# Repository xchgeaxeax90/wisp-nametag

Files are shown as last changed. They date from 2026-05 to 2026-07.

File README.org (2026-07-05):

#+title: Wisp Light-up Nametag

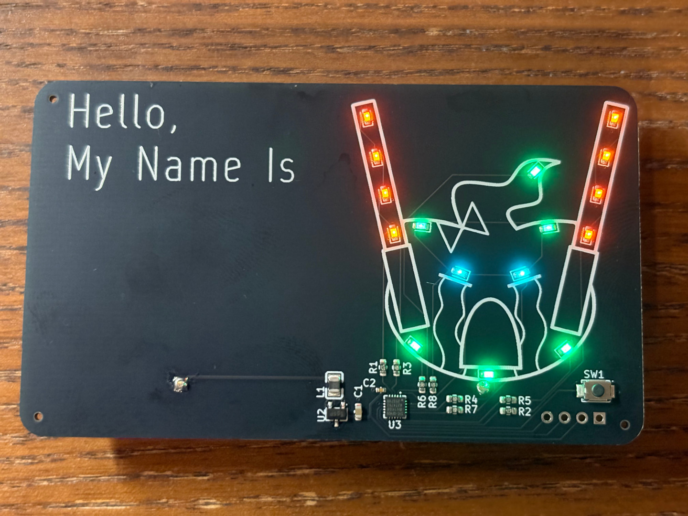
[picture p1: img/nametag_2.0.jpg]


This repository contains the PCB design and software for the light up
nametag I will be giving out at Offkai Expo 2026. 

* Usage
** Battery

*NOTE: Please be very careful to insert the battery with the correct polarity in the battery holder. Failure to do so may result in destruction of the device*

The Badge is powered by a 1.5V AAA battery. While I have not tested it, it should be compatible with rechargable AAA cells or lithium rechargable cells, provided the battery voltage is below 3 volts.

While powered down, the badge draws a small amount of current from the battery at all times. When storing the badge for long periods of time (weeks-months), please remove the battery so as to avoid draining the battery or causing it to leak.

*** User Interface

- Tap the button on the bottom right to change the blink pattern
- Press and hold the button on the bottom right for about 2 seconds, then release to enter brightness mode. The LEDs will stop blinking and remain on continuously
- When in brightness mode, tap the button to change the brightness
- To exit brightness mode, press and hold the button for about 2 seconds, then release. The LEDs should begin blinking again
- To power off the device, press and hold the button until the LEDs turn off
- To power the device back on, tap the button again

* Manufacture

** Hardware
The PCBs I made were ordered from [[https://jlcpcb.com][JLCPCB]], through their PCB Assembly
service. The design files under the [[https://github.com/xchgeaxeax90/wisp-nametag/releases/tag/v2.0][v2.0 Manufacturing Files]] release
can be uploaded to JLCPCB's automatic quote system to order either
bare PCBs or assembled boards.

*** Parts

The Bill of Materials is below. When viewing the BOM from Kicad, the JLCPCB/LCSC part ids should be taken as the reference, some of the part numbers in the schematic are incorrect

| Part Name            | Designator              | Comment                                                                |
|----------------------+-------------------------+------------------------------------------------------------------------|
| TZ-P2-0603GTCS1-0.6T | D9,D10,D11,D12,D13,D14  | 0603 SMD LED – Emerald Green 520nm                                     |
| TS-1088-AR02016      | SW1                     | 3.9x3.0mm SPST Momentary Button                                        |
| CL10A226MQ8NRNC      | C1                      | 0603 22uf ceramic capacitor                                            |
| MPL2016S2R2MHT       | L1                      | 0806 2.2 uH inductor                                                   |
| BL8536CB3TR36        | U2                      | 0.9V-3.3V Ultra Low Voltage Boost Converter                            |
| 0603WAF470JT5E       | R1,R2                   | 0603 47 Ohm Resistor                                                   |
| STC8H1K08-36I-QFN20  | U3                      | STC8H1K08 24MHz microcontroller                                        |
| CL05B104KO5NNNC      | C2                      | 0402 100nF Capacitor                                                   |
| LTST-C190KFKT        | D1,D2,D3,D4,D5,D6,D7,D8 | 0603 SMD LED – Orange 605nm                                            |
| SMLD12E3N1WT86       | D15,D16                 | 0603 SMD LED – Cyan 496nm                                              |
| 0603WAF3000T5E       | R3,R4,R5,R6,R7,R8       | 0603 300 Ohm Resistor                                                  |
| 2466                 | BT1                     | AAA Battery Holder (not included in JLCPCB quote, hand solder on back) |

Note: If manufacturing this yourself, consider using the
SMLD12E2N1WT86 505nm Blue-Green LED in place of the 520 Emerald Green
LED. It looks much closer to mint green, but is much more difficult
and expensive to source

** Software

The software loaded on the badges I gave (or will give) out can be
found at the [[https://github.com/xchgeaxeax90/wisp-nametag/releases/tag/v2.0-software][v2.0 Software]] release. This contains the entire source
code as well as prebuilt binaries that can be loaded directly onto the
boards.

*** Programming

The microcontroller can be programmed using a 3.3V USB to UART cable and the [[https://github.com/grigorig/stcgal][STCGal programmer software]].

1. Completely remove power from the board. The board cannot just be put to sleep using the button, it must be entirely powered off, with the battery removed
2. Connect the microcontroller's TX and RX pins to the UART. These pins can be found on the programming header on the bottom left of the PCB when viewed from the back. If you're good, you can likely do this by just shoving pins in the holes instead of soldering them in place.
3. Start =stcgal=, replacing =/dev/ttyUSB0= with your USB to UART's serial port device 
   
#+BEGIN_SRC bash
  stcgal -p /dev/ttyUSB0 -P stc8g --trim 24000 path/to/app.hex
#+END_SRC

4. Power on the board - I like to use alligator clips to clip directly on to the battery terminals, but you can also just insert the battery

5. The programmer should automatically begin downloading the code to the microcontroller

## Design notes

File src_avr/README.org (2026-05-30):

* Datasheets and application notes:
  - AVR16DD20 Datasheet: https://ww1.microchip.com/downloads/aemDocuments/documents/MCU08/ProductDocuments/DataSheets/AVR32-16DD20-14-Complete-DataSheet-DS40002413.pdf
  - Getting started with TCA Technical Brief: https://ww1.microchip.com/downloads/aemDocuments/documents/MCU08/ApplicationNotes/ApplicationNotes/TB3217-Getting-Started-with-TCA-DS90003217.pdf
    - This will be used to drive the 6 PWM channels controlling the
      lights on the face. Two sets of lights (the eyes and top l/r)
      are shared and will be multiplexed
  - Getting started with TCB Technical Brief: https://ww1.microchip.com/downloads/en/DeviceDoc/TB3214-Getting-Started-with-TCB-90003214A.pdf
    - This timer (of which there are two) will be used to generate a
      periodic interrupt to switch between the eye and top l/r multiplexing
  - Getting started with TCD Technical Brief: https://ww1.microchip.com/downloads/aemDocuments/documents/MCU08/ApplicationNotes/ApplicationNotes/TB3212-Getting-Started-with-TCD-DS90003212.pdf
    - This timer will be used to generate the PWM signals for the penlights
  - Getting started with RTC Technical Brief: https://ww1.microchip.com/downloads/en/Appnotes/TB3213-Getting-Started-with-RTC-DS90003213B.pdf
    - This may or may not be used to trigger a PWM setting update -
      Either this, the second timer B, or an extra counter and hook
      into the multiplex interrupt will do it
  - Getting started with CCL Technical Brief: https://ww1.microchip.com/downloads/en/AppNotes/TB3218-Getting-Started-with-CCL-90003218A.pdf
    - This might be needed to debounce/filter the signal from the
      button (which conveniently is on a CCL input, totally by accident)
  
  - Hacking an Attiny817XPlained to be a UPDI programmer: https://www.jsykora.info/2019/04/avr-updi-programmer-from-attiny817-xplained-mini/
  - Generating PWM signals with TCD Appnote: https://ww1.microchip.com/downloads/aemDocuments/documents/MCU08/ApplicationNotes/ApplicationNotes/Generating-PWMSignals-Using-TCD-with-HF-Input-DS90003236C.pdf

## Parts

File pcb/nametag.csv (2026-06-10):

Comment | Designator | Footprint | LCSC
Battery_Cell | BT1 | Battery:BatteryHolder_Keystone_2466_1xAAA
GMC10X5R226M10NT | C1 | Capacitor_SMD:C_0603_1608Metric | C59461
100n | C2 | Capacitor_SMD:C_0402_1005Metric | C1525
LTST-C190KFKT | D1,D2,D3,D4,D5,D6,D7,D8 | LED_SMD:LED_0603_1608Metric | C157740
SMLD12E2N1WT86 | D15,D16 | LED_SMD:LED_0603_1608Metric | C2846641
SMLD12E3N1WT86 | D9,D10,D11,D12,D13,D14 | LED_SMD:LED_0603_1608Metric | C779453
WIP201612S-2R2MLDG | L1 | EasyEDA:L0806 | C42215
47 | R1,R2 | Resistor_SMD:R_0603_1608Metric | C23182
300 | R3,R4,R5,R6,R7,R8 | Resistor_SMD:R_0603_1608Metric | C23025
TS-1088-AR02016 | SW1 | EasyEDA:SW-SMD_L3.9-W3.0-P4.45
TestPoint | TP1,TP2,TP3,TP4 | TestPoint:TestPoint_Pad_D1.0mm
BL8536CB3TR36 | U2 | EasyEDA:SOT-23-3_L2.9-W1.6-P1.90-LS2.8-BR
STC8H1K08-QFN20 | U3 | EasyEDA:QFN-20_L3.0-W3.0-P0.40-BL-EP1.7 | C915674

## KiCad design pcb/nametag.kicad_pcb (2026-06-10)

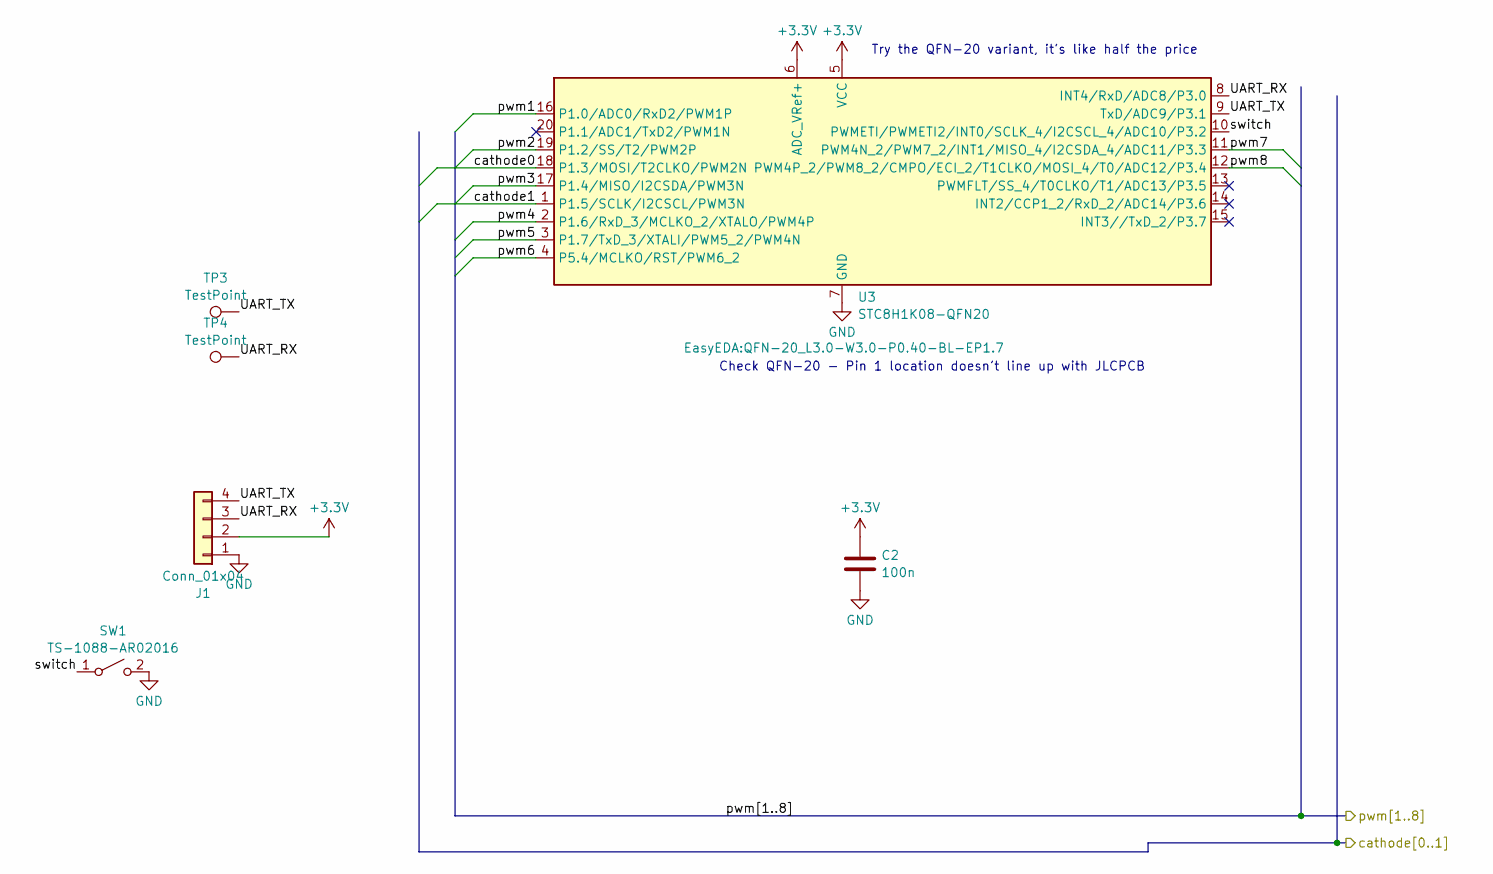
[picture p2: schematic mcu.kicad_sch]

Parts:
C2: 100n; C_0402_1005Metric; LCSC C1525
J1: Conn_01x04; PinSocket_1x04_P2.54mm_Vertical
SW1: TS-1088-AR02016; SW-SMD_L3.9-W3.0-P4.45
TP3, TP4: TestPoint; TestPoint_Pad_D1.0mm
U3: STC8H1K08-QFN20; QFN-20_L3.0-W3.0-P0.40-BL-EP1.7; LCSC C915674

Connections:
+3.3V: C2.1, J1.2, U3.5 (VCC), U3.6 (ADC_VRef+); also elsewhere on the board
/Mcu/UART_RX: J1.3, TP4.1 (1_1), U3.8 (INT4/RxD/ADC8/P3.0)
/Mcu/UART_TX: J1.4, TP3.1 (1_1), U3.9 (TxD/ADC9/P3.1)
/Mcu/cathode0: U3.18 (P1.3/MOSI/T2CLKO/PWM2N); also elsewhere on the board
/Mcu/cathode1: U3.1 (P1.5/SCLK/I2CSCL/PWM3N); also elsewhere on the board
/Mcu/pwm1: U3.16 (P1.0/ADC0/RxD2/PWM1P); also elsewhere on the board
/Mcu/pwm2: U3.19 (P1.2/SS/T2/PWM2P); also elsewhere on the board
/Mcu/pwm3: U3.17 (P1.4/MISO/I2CSDA/PWM3N); also elsewhere on the board
/Mcu/pwm4: U3.2 (P1.6/RxD_3/MCLKO_2/XTALO/PWM4P); also elsewhere on the board
/Mcu/pwm5: U3.3 (P1.7/TxD_3/XTALI/PWM5_2/PWM4N); also elsewhere on the board
/Mcu/pwm6: U3.4 (P5.4/MCLKO/RST/PWM6_2); also elsewhere on the board
/Mcu/pwm7: U3.11 (PWM4N_2/PWM7_2/INT1/MISO_4/I2CSDA_4/ADC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); also elsewhere on the board
/Mcu/pwm8: U3.12 (PWM4P_2/PWM8_2/CMPO/ECI_2/T1CLKO/MOSI_4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); also elsewhere on the board
/Mcu/switch: SW1.1 (A), U3.10 (PWMETI/PWMETI2/INT0/SCLK_4/I2CSCL_4/ADC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)
GND: C2.2, J1.1, SW1.2 (B), U3.7 (GND), U3.21 (EP); also elsewhere on the board

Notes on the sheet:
Check QFN-20 - Pin 1 location doesn't line up with JLCPCB
Try the QFN-20 variant, it's like half the price

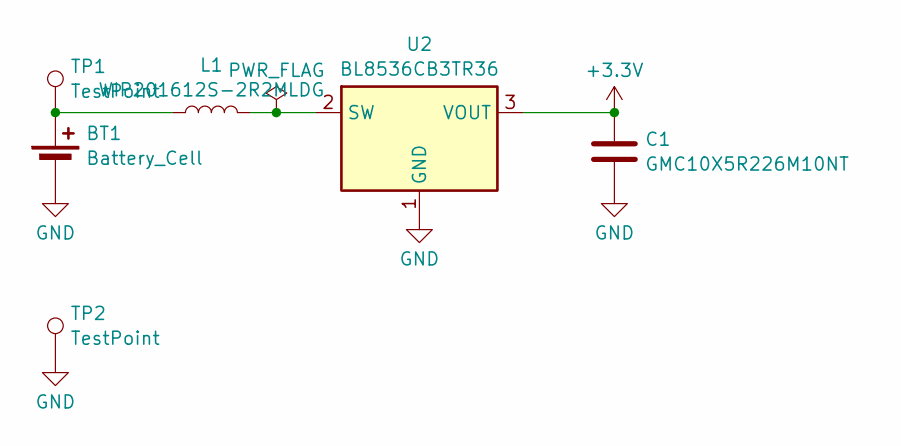
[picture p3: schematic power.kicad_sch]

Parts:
BT1: Battery_Cell; BatteryHolder_Keystone_2466_1xAAA
C1: GMC10X5R226M10NT; C_0603_1608Metric; LCSC C59461
L1: WIP201612S-2R2MLDG; L0806; LCSC C42215
TP1, TP2: TestPoint; TestPoint_Pad_D1.0mm
U2: BL8536CB3TR36; SOT-23-3_L2.9-W1.6-P1.90-LS2.8-BR

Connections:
+3.3V: C1.1, U2.3 (VOUT); also elsewhere on the board
GND: BT1.2 (-), C1.2, TP2.1 (1_1), U2.1 (GND); also elsewhere on the board
unnamed: BT1.1 (+), L1.1, TP1.1 (1_1)
unnamed: L1.2, U2.2 (SW)

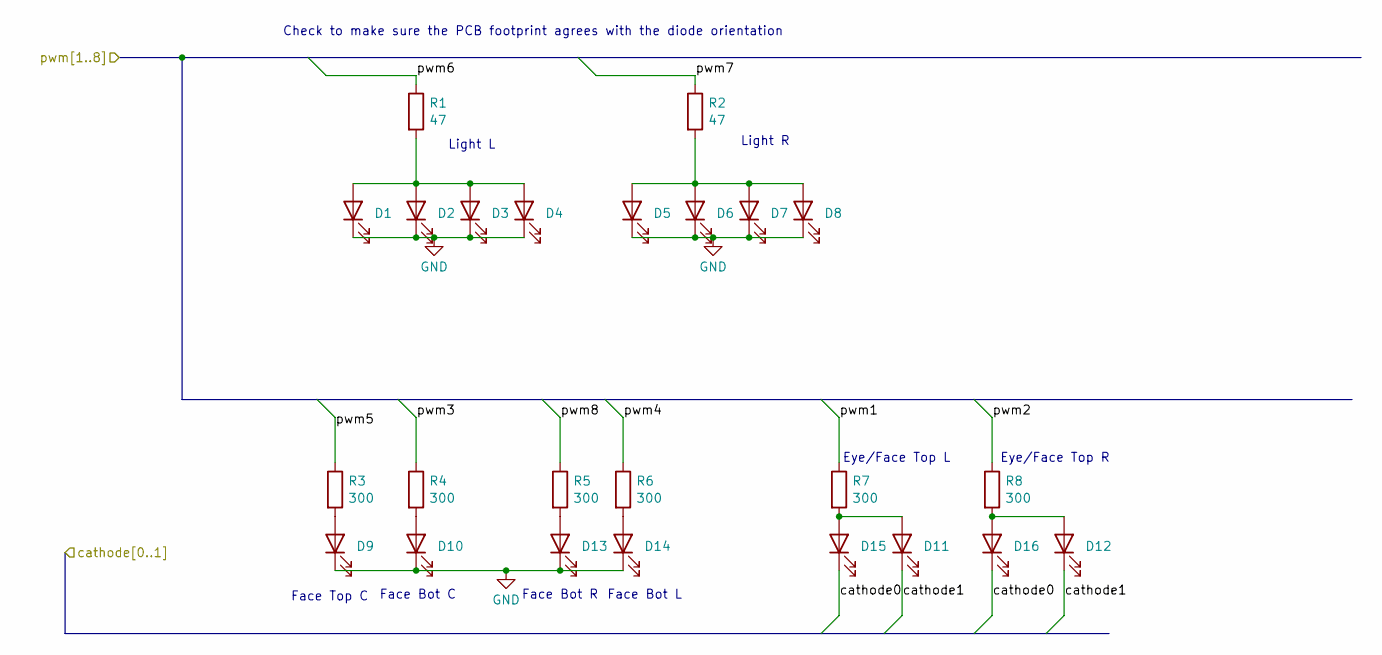
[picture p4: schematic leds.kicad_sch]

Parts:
D1, D2, D3, D4, D5, D6, D7, D8: LTST-C190KFKT; LED_0603_1608Metric; LCSC C157740
D9, D10, D11, D12, D13, D14: SMLD12E3N1WT86; LED_0603_1608Metric; LCSC C779453
D15, D16: SMLD12E2N1WT86; LED_0603_1608Metric; LCSC C2846641
R1, R2: 47; R_0603_1608Metric; LCSC C23182
R3, R4, R5, R6, R7, R8: 300; R_0603_1608Metric; LCSC C23025

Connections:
/Mcu/cathode0: D15.1 (K), D16.1 (K); also elsewhere on the board
/Mcu/cathode1: D11.1 (K), D12.1 (K); also elsewhere on the board
/Mcu/pwm1: R7.1; also elsewhere on the board
/Mcu/pwm2: R8.1; also elsewhere on the board
/Mcu/pwm3: R4.1; also elsewhere on the board
/Mcu/pwm4: R6.1; also elsewhere on the board
/Mcu/pwm5: R3.1; also elsewhere on the board
/Mcu/pwm6: R1.1; also elsewhere on the board
/Mcu/pwm7: R2.1; also elsewhere on the board
/Mcu/pwm8: R5.1; also elsewhere on the board
GND: D1.1 (K), D2.1 (K), D3.1 (K), D4.1 (K), D5.1 (K), D6.1 (K), D7.1 (K), D8.1 (K), D9.1 (K), D10.1 (K), D13.1 (K), D14.1 (K); also elsewhere on the board
unnamed: D1.2 (A), D2.2 (A), D3.2 (A), D4.2 (A), R1.2
unnamed: D5.2 (A), D6.2 (A), D7.2 (A), D8.2 (A), R2.2
unnamed: D9.2 (A), R3.2
unnamed: D10.2 (A), R4.2
unnamed: D11.2 (A), D15.2 (A), R7.2
unnamed: D12.2 (A), D16.2 (A), R8.2
unnamed: D13.2 (A), R5.2
unnamed: D14.2 (A), R6.2

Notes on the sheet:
Face Bot L
Eye/Face Top R
Light L
Light R
Face Bot C
Check to make sure the PCB footprint agrees with the diode orientation
Eye/Face Top L
Face Bot R
Face Top C

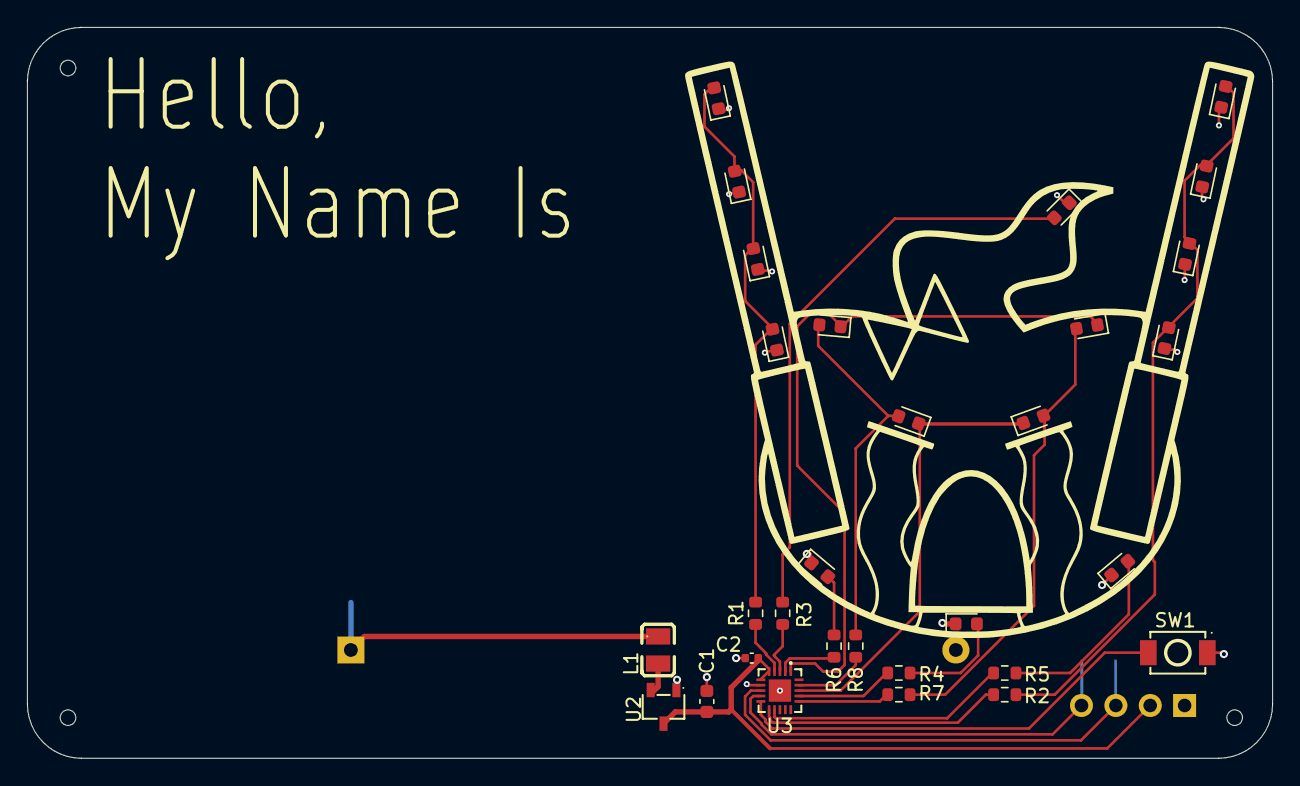
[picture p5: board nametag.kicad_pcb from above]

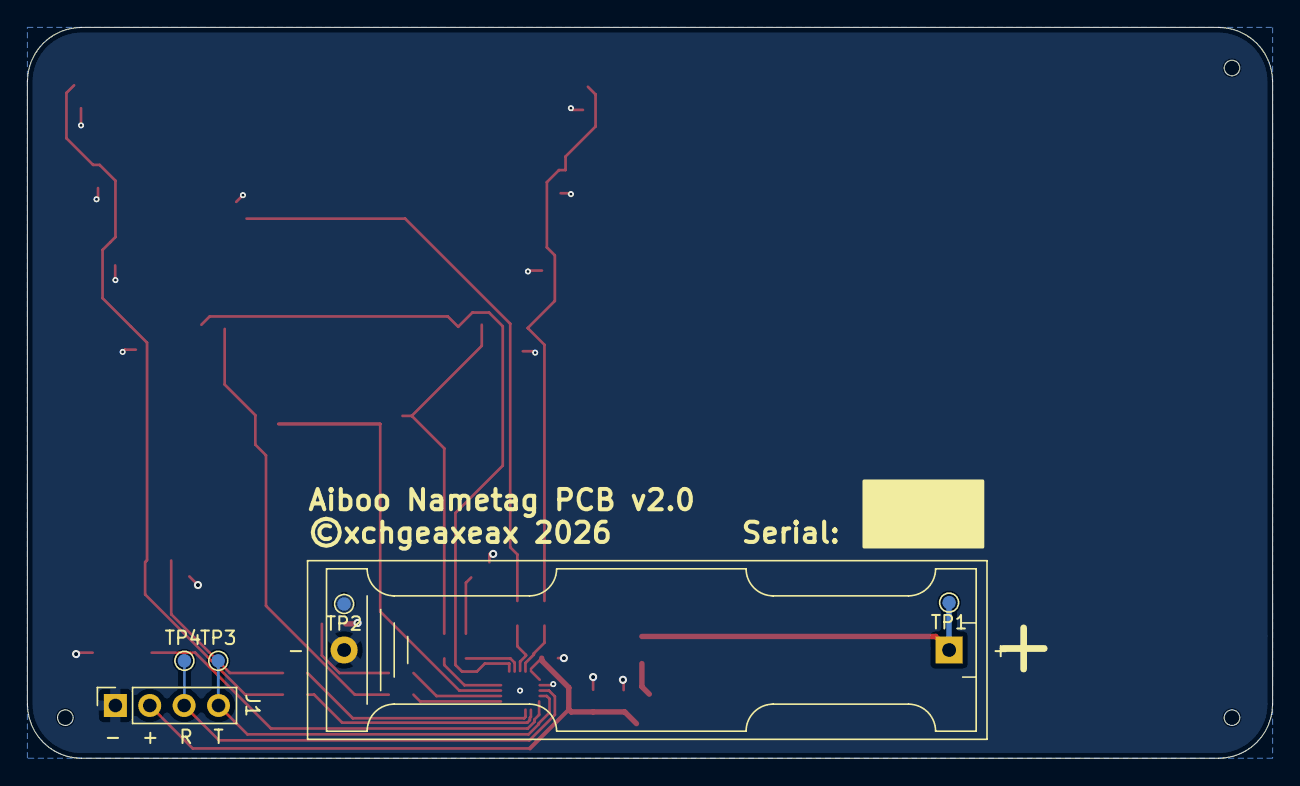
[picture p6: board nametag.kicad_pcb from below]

Board: 2 copper layers, 92.0 x 54.0 mm, 39 parts (6 on the bottom side), 25 nets.

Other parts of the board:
HO1, HO2, HO3: JLC PCBA Mounting Hole

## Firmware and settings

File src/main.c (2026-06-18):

#include "fw_hal.h"
#include "pins.h"
#include "pwm.h"
#include "timer.h"
#include "animation.h"
#include "state_machine.h"
#include "debug.h"

/* TODO determine if we actually need the button state bit */
volatile __idata uint16_t button_timeout = 0;
volatile __BIT button_state = 0;
void poll_button(void){
    /* Button is active low */
    if(!BUTTON_PIN_BIT){
        if(!button_state){
            button_timeout = 0;
        } else {
            button_timeout += 1;
        }
        button_state = 1;
    } else {
        button_state = 0;
    }
}

/* Selects which cathode to enable */

// Called periodically by TCB0 to update the multiplexing for the eyes and top LEDs

static volatile __BIT eye_en = 0;
INTERRUPT_USING(Timer2_Routine, EXTI_VectTimer2, 1) {
    uint8_t p_sw2_save = P_SW2;
    poll_button();
    /* Disable cathodes */
    if(update_animation()){

        write_pwm();
    }
    /* Disable both cathodes between PWM setting update and when the
    setting is loaded to the capture compare unit */
    CATHODE0_PIN_BIT = SET;
    CATHODE1_PIN_BIT = SET;
    write_pwm_multiplexed(eye_en);
    /* Enable the interrupt for PWM overflow to synchronize cathode updates to PWM period */

    /* Enable the PWM update interrupt so the cathode setting can be updated synchronously to the PWM capture compare unit */
    SFRX_SET(PWMA_IER, 0);
    P_SW2 = p_sw2_save;
}

INTERRUPT_USING(PWMA_Routine, EXTI_VectPWMA, 2) {
    uint8_t p_sw2_save = P_SW2;
    if(eye_en){
        /* Cathode 0 is connected to the eyes, it should be low */
        CATHODE0_PIN_BIT = RESET;
        CATHODE1_PIN_BIT = SET;
    } else {
        /* Cathode 1 is connected to the head, it should be low */
        CATHODE0_PIN_BIT = SET;
        CATHODE1_PIN_BIT = RESET;
    }
    eye_en = !eye_en;
    SFRX_RESET(PWMA_IER, 0);
    P_SW2 = p_sw2_save;
}

void deep_sleep(void){
    /* stop_pwm(); */
    /* stop_timer(); */
    disable_pins();
    /* Enable the INT0 interrupt on P3.2 */
    EXTI_Int0_SetTrigByFall;
    EXTI_Int0_SetIntState(HAL_State_ON);
    /* TODO add disabling of the GPIO outputs */

    /* Put the MCU to sleep */
    RCC_SetPowerDownMode(HAL_State_ON);
    /* Disable the interrupt */
    EXTI_Int0_SetIntState(HAL_State_OFF);
    /* Software reset */
    //IAP_SoftReset();
    /* For some reason, this doesn't seem to work right, the system comes out of sleep with the animation stopped */
    setup_gpio();
    setup_pwm();
    setup_timer2_interrupt();
    set_animation_state();
}

/* With no clock division, the multiplexing runs at 121Hz and PWM runs at 93 kHz */
/* At 1MHz, the multiplexing runs at 114Hz, and the PWM at 3.9 kHz */

void setup_clock(void){
    RCC_SetCLKDivider(24);
}

int main(void){
    setup_clock();
    //SYS_SetClock();
    setup_gpio();
    setup_pwm();

    setup_timer2_interrupt();
    DEBUG_INIT(9600);

    while(1) {
        /* Atomically read button state and timeout into local variables */
        EXTI_Global_SetIntState(HAL_State_OFF);
        uint16_t timeout = button_timeout;
        uint8_t state = button_state;
        EXTI_Global_SetIntState(HAL_State_ON);
        /* Use button state and timeout to determine how long the button was held */
        if(state == 0 && timeout > 20 && timeout < 300){
            short_button_press();
        }
        if(state == 0 && timeout >= 300 && timeout < 700){
            long_button_press();
        }
        if(state == 1 && timeout == 700){
            DEBUG_PRINTLN("select_off_animation()");
            select_off_animation();
        }
        if(state == 0 && timeout >= 700){
            DEBUG_PRINTLN("deep_sleep()");
            deep_sleep();
        }
        if(state == 0 && timeout != 0){
            EXTI_Global_SetIntState(HAL_State_OFF);
            button_timeout = 0;
            EXTI_Global_SetIntState(HAL_State_ON);
        }

        /* Loop, wait for interrupts */
        RCC_SetIdleMode(HAL_State_ON);
    }
}

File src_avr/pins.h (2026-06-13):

#pragma once

// Lightstick L - PWM6
// Lightstick R - PWM7
// Face Bottom L - PWM3
// Face Bottom C - PWM0
// Face Bottom R - PWM1
// Eye L - PWM5 Cathode 0
// Eye R - PWM4 Cathode 0
// Face Top L - PWM5 Cathode 1
// Face Top R - PWM4 Cathode 1
// Face Top C - PWM2

#define PWM0to5_PORT PORTA
#define PWM0_bm PIN0_bm
#define PWM1_bm PIN1_bm
#define PWM2_bm PIN2_bm
#define PWM3_bm PIN3_bm
#define PWM4_bm PIN4_bm
#define PWM5_bm PIN5_bm

#define PWM67_PORT PORTD
#define PWM6_bm PIN4_bm
#define PWM7_bm PIN5_bm

#define CATHODE_PORT PORTA
#define CAT0_bi PIN6_bi
#define CAT1_bi PIN7_bi
#define CAT0_bm PIN6_bm
#define CAT1_bm PIN7_bm

#define BTN_PORT PORTC
#define BTN_bm PIN1_bm

#define PORTC_EXTRA (PIN2_bm | PIN3_bm)
#define PORTD_EXTRA (PIN6_bm | PIN7_bm)

void init_pins(void);
void enable_button_interrupt(void);
void disable_button_interrupt(void);

void disable_pins(void);

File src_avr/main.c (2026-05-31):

#include <avr/io.h>
#include <avr/interrupt.h>
#include <avr/sleep.h>
#include <util/delay.h>
#include "pwm.h"
#include "pins.h"
#include "timer.h"
#include "animation.h"
#include "state_machine.h"


void init_clock();
volatile uint16_t button_timeout = 0;
volatile uint8_t button_state = 0;
void poll_button(void){
    if(BTN_PORT.IN & BTN_bm){
	if(!button_state){
	    button_timeout = 0;
	} else {
	    button_timeout += 1;
	}
	button_state = 1;
    } else {
	button_state = 0;
    }
}

// Called periodically by TCB0 to update the multiplexing for the eyes and top LEDs
static volatile uint8_t eye_en = 0;

ISR(TCB0_INT_vect) {
    poll_button();
    CATHODE_PORT.OUTSET = CAT0_bm | CAT1_bm;
    // Toggle the multiplex driver pins
    if(update_animation()){

	write_pwm(&animation_ptr->pwm_settings);
    }
    eye_en = ~eye_en;
    // Set the actual multiplex pins on the TCA interrupt, so they're synced to the PWM period
    TCA0.SPLIT.INTFLAGS = TCA_SPLIT_HUNF_bm;
    TCA0.SPLIT.INTCTRL = TCA_SPLIT_HUNF_bm;
    TCB0.INTFLAGS = TCB_CAPT_bm;
}

ISR(TCA0_HUNF_vect) {
    if(eye_en){
	CATHODE_PORT.OUTCLR = CAT0_bm;
    } else {
	CATHODE_PORT.OUTCLR = CAT1_bm;
    }
    write_pwm_multiplexed(&animation_ptr->pwm_settings, eye_en);
    TCA0.SPLIT.INTFLAGS = TCA_SPLIT_HUNF_bm;
    TCA0.SPLIT.INTCTRL = 0;
}

void deep_sleep(void){
    stop_pwm();
    disable_pins();
    disable_timer();
    enable_button_interrupt();
    set_sleep_mode(SLEEP_MODE_PWR_DOWN);
    sleep_mode();
    disable_button_interrupt();
    init_pins();
    init_timer();
    init_pwm();
}

int main(void){
    init_clock();

    init_pins();
    //init_button_interrupt();

    init_pwm();

    init_timer();

    sei();
    while(1){
        cli();
        uint16_t timeout = button_timeout;
        uint8_t state = button_state;
        sei();
        if(state == 0 && timeout > 20 && timeout < 300){
            short_button_press();
        }
        if(state == 0 && timeout >= 300 && timeout < 700){
            long_button_press();
        }
        /* use == instead of >= so as not to continuously call
           select_off_animation() every time we poll the button
           state. Doing so causes update_animation to never fire because
           the animation timeout is never reached */
        if(state == 1 && timeout == 700){
            select_off_animation();
        }
        if(state == 0 && timeout >= 700){
            deep_sleep();
        }
        if(state == 0 && timeout != 0){
            cli();
            button_timeout = 0;
            sei();
        }
        set_sleep_mode(SLEEP_MODE_IDLE);
        sleep_mode();
    }
}


void init_clock(void){
    // Select the HF RC oscillator
    _PROTECTED_WRITE(CLKCTRL.MCLKCTRLA, CLKCTRL_CLKSEL_OSCHF_gc);
    // Wait until clock switch is over
    while(CLKCTRL.MCLKSTATUS & CLKCTRL_SOSC_bm) {}

    // Select 1MHz, no run standby
    _PROTECTED_WRITE(CLKCTRL.OSCHFCTRLA, CLKCTRL_FRQSEL_1M_gc);

}

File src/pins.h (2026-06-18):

#pragma once

/*
  Pin selections:
  - PWMA1 - Alt 0 - P1.0 - Eye/Face Top R
  - PWMA2 - Alt 0 - P1.2 - Eye/Face Top L
  - PWMA3 - Alt 0 - P1.4 - Face Bot C
  - PWMA4 - Alt 0 - P1.6 - Face Bot L
  - PWMB5 - Alt 1 - P1.7 - Face Top C
  - PWMB6 - Alt 1 - P5.4 - Light L
  - PWMB7 - Alt 1 - P3.3 - Light R
  - PWMB8 - Alt 1 - P3.4 - Face Bot R
  - Button - P3.2 - INT0 - Internal Pullup to VCC
  - Cathode 0 - P1.3
  - Cathode 1 - P1.5 
 */

#define BUTTON_PORT GPIO_Port_3
#define BUTTON_PIN GPIO_Pin_2
#define BUTTON_PIN_BIT P32
#define CATHODE0_PIN_BIT P13
#define CATHODE1_PIN_BIT P15

void setup_gpio(void);

void disable_pins(void);

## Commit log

2025-01-10 Swap to STC8H1K08 and work on JLCPCB assembly support
    [leds.kicad_sch, mcu.kicad_sch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]
2026-05-30 More edits to PCB design
    - Change a couple of parts - voltage regulator - to use LCSC parts
    - Increase width of the nametag PCB
    - redo layout a bit
    [leds.kicad_sch, mcu.kicad_sch, nametag.kicad_pcb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]
2026-05-30 Enable all PWM channels on the device
2026-05-30 Remove most of the HAL calls in PWM setup
    Each HAL call is wrapped in SFRX_ON() and SFRX_OFF() - this uses a
    considerable amount of extra memory
2026-05-30 Update PCB to reflect PWM pin assignments
    [mcu.kicad_sch, nametag.kicad_pcb]
2026-05-30 Enable timer 2 interrupt
2026-05-31 Update PCB with new naming of PWM channels
    [leds.kicad_sch, mcu.kicad_sch, nametag.kicad_pcb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]
2026-05-31 Get basic PWM animation working
2026-05-31 Get LED multiplexing working
2026-05-31 Synchronize PWM setting updates to the cathode multiplexing
2026-05-31 Attempt to get sleep working, the only way to make it restart is a software reset
    [main.c, pins.c, pins.h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]
2026-06-03 Small changes for manufacturability
    [leds.kicad_sch, mcu.kicad_sch, nametag.kicad_pcb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]
2026-06-06 Try swapping to a qfn part instead of tssop-20
    [leds.kicad_sch, mcu.kicad_sch, nametag.kicad_pcb]
2026-06-07 Add JLC PCBA Mounting holes
    [nametag.kicad_pcb]
2026-06-07 Enlarge the PCB a bit
    [mcu.kicad_sch, nametag.kicad_pcb]
2026-06-07 Update footprints from LCSC EasyEDA Library
    [leds.kicad_sch, mcu.kicad_sch, nametag.kicad_pcb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]
2026-06-07 Redo some of the layout, move button
    [mcu.kicad_sch, nametag.kicad_pcb, power.kicad_sch]
2026-06-10 Submit files to JLCPCB for manufacture
    [leds.kicad_sch, mcu.kicad_sch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]
2026-06-13 Add debug prints, fix issue with off animation
    [animation.c, main.c]
2026-06-13 Fix sleep mode current issue
    [pins.c]
2026-06-13 Fix some bugs in the avr version, maybe reduce power consumption?
    [animation.c, pins.c, pins.h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]
2026-06-14 Potentially fix bug in the avr sleep entry
    [pins.c, pwm.c]
2026-06-14 I think fix some potential bugs?
    [main.c, pwm.c]
2026-06-18 Fixup pin assignments to match the qfn pcb pinout
    [pins.c, pins.h, pwm.c]
2026-06-18 Don't perform a reset after deep sleep
    [main.c, pins.h]
2026-06-18 Hack in a scale for the green leds to tame them a bit
2026-06-19 Rework makefile, add argument to scale the green LEDs
2026-07-05 Update BOM table, add Keystone 2466 battery holder

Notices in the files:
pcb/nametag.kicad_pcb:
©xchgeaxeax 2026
